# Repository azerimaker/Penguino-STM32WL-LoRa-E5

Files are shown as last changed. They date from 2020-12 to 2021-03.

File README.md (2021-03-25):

## Penguino-STM32WL-LoRa-E5
 Seeedstudio's [LoRa-E5 STM32WLE5JC](https://www.seeedstudio.com/LoRa-E5-Wireless-Module-p-4745.html) module was recently announced, and I took the liberty of designing a Penguino Feather breakout board for it. Hopefully OSHW community would benfit from it. 

## About the Penguino Feather breakout
Managed to fit everything on a +2 layer (H1.6mm) low-cost PCB. Careful design choices allowed to have a good GND plane on the back to to achieve good (theoretical) RF performance. 

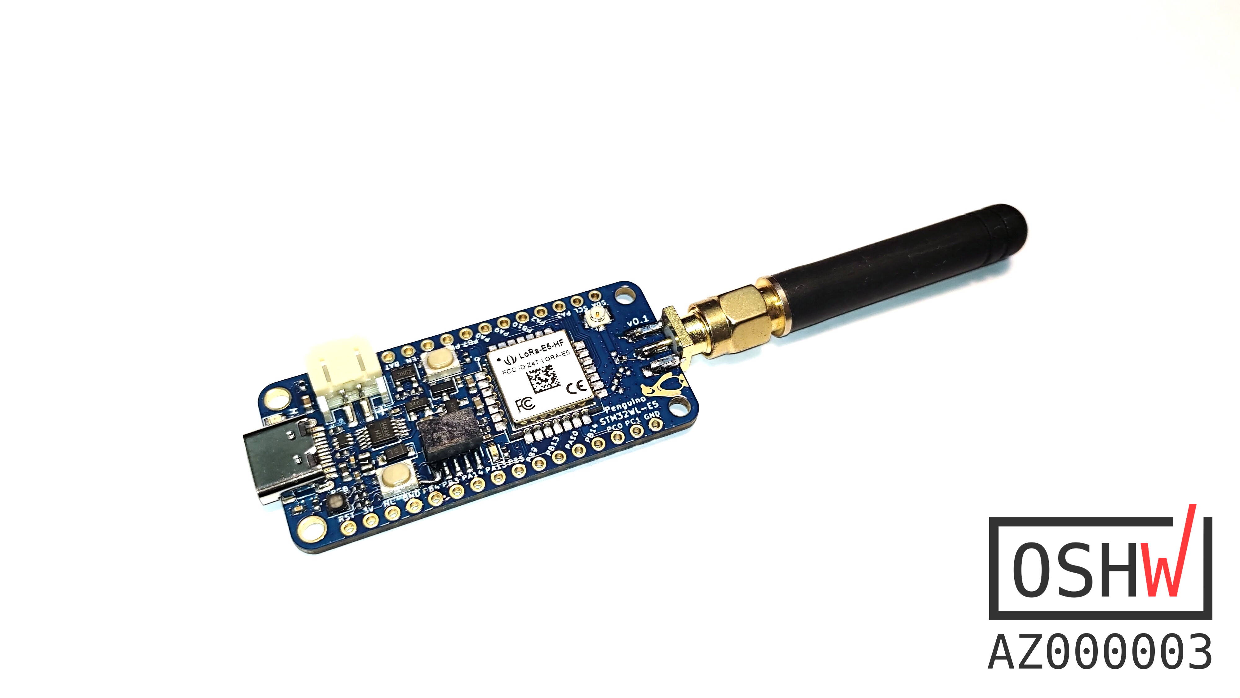
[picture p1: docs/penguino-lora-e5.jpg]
Penguino-STM32WL-LoRa-E5

_Current version: 0.1_

Board requirements are standard: 
- 6mil traces/clearance
- 0.3mm drill

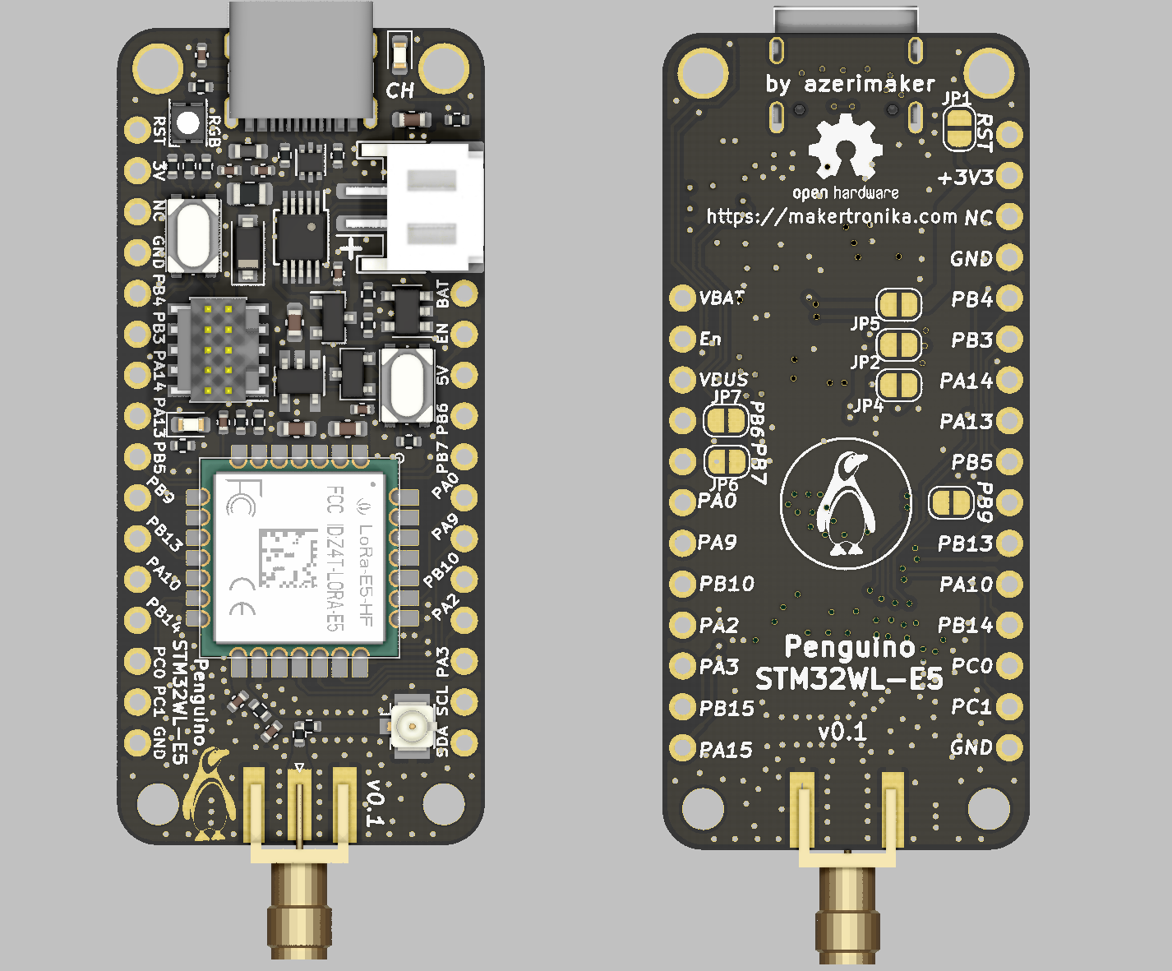
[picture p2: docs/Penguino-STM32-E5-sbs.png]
Penguino-STM32WL-LoRa-E5-back


### Specs (SoC): 
- [STM32WLE5JC](https://www.st.com/en/microcontrollers-microprocessors/stm32wle5jc.html) Wireless SoC
- ARM Cortex M4 ultra-low-power MCU
- Integrated SX1262 RF transciever
- Frequency range: 150 MHz to 960 MHz.
- Modulation: LoRa®, (G)FSK, (G)MSK and BPSK
- Transmitter power: programmable up to +22 dBm 

### Specs ([LoRa-E5 module](](https://www.seeedstudio.com/LoRa-E5-Wireless-Module-p-4745.html))): 
- Frequency range: EU868/US915/AU915/AS923/KR920/IN865 (high-band design). FCC and CE Certified
- Ultra-low Power Consumption: as low as 2.1uA sleep current (WOR mode)
- High Performance: TXOP=22dBm@868/915MHz; -136.5dBm sensitivity for SF12 with 125KHz BW 
- Long Distance Use: 158dB link budget
- Size: 12mm * 12mm * 2.5mm 28 pins SMT
- For further specs plese see the respective product pages. 

### License:
- Hardware license: CERN-OHL-S v2
- Software license: under MIT unless otherise indicated 
- Documentation license:  CC BY-SA 4.0 International.

OSHW License

## Open Source Hardware
This board is an OSHWA approved design: [AZ000003](https://certification.oshwa.org/az000003.html)

### Contact:
If you have any question or comments please feel free to open an issue (or a discussion or drop me a message at [@azerimaker](https://twitter.com/azerimaker).

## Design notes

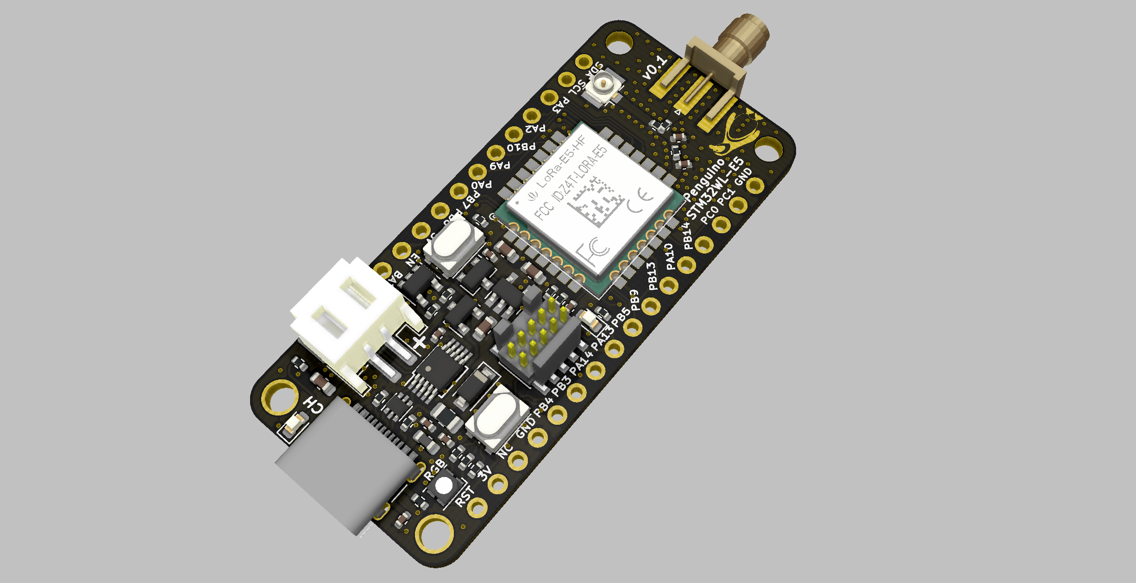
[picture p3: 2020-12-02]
docs/Penguino-STM32-E5.PNG

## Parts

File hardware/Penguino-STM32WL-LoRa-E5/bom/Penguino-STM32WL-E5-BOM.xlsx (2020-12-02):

Item | Qty | Reference(s) | MPN | MPN_ALT | Seeed SKU | Value | Footprint | URL
1 | 2 | C1, C2 | CC0402KRX7R9BB103 | ~ | 302010006 | 10nF | Capacitor_SMD:C_0402_1005Metric | https://lcsc.com/product-detail/Multilayer-Ceramic-Capacitors-MLCC-SMD-SMT_YAGEO-CC0402KRX7R9BB103_C60133.html
2 | 3 | C3, C5, C6 | CC0603KRX5R6BB106 | ~ | 302010103 | 10uF | Capacitor_SMD:C_0603_1608Metric | https://lcsc.com/product-detail/Others_YAGEO-CC0603KRX5R6BB106_C326057.html
3 | 4 | C4, C7, C10, C13 | GRM155R61A104KA01D | ~ | 302010037 | 100nF | Capacitor_SMD:C_0402_1005Metric | https://lcsc.com/product-detail/Multilayer-Ceramic-Capacitors-MLCC-SMD-SMT_Murata-Electronics-GRM155R61A104KA01D_C76997.html
4 | 1 | C8 | CC0603KRX5R6BB475 | ~ | 302010111 | 4.7uF | Capacitor_SMD:C_0603_1608Metric | https://lcsc.com/product-detail/Multilayer-Ceramic-Capacitors-MLCC-SMD-SMT_YAGEO-CC0603KRX5R6BB475_C109456.html
5 | 0 | C9, C11 | DNM | ~ |  | DNM | Capacitor_SMD:C_0402_1005Metric | ~
6 | 1 | D1 | 19-217-Y5C-AM1N1VY-3T | ~ | 304090044 | CH_YELLOW | LED_SMD:LED_0603_1608Metric | https://lcsc.com/product-detail/Others_Everlight-Elec-19-217-Y5C-AM1N1VY-3T_C282130.html
7 | 1 | D2 | B5819W | ~ | 304020034 | B5819W | Diode_SMD:D_SOD-123 | https://lcsc.com/product-detail/Schottky-Barrier-Diodes-SBD_AnBon-B5819W_C541627.html
8 | 1 | D3 | FM-B2020RGBA-HG | ~ | ~ | FM-B2020RGBA RGB LED | LED_SMD:LED_Cree-PLCC4_2x2mm_CW | https://lcsc.com/product-detail/Light-Emitting-Diodes-LED_Foshan-NationStar-Optoelectronics-FM-B2020RGBA-HG_C108793.html
9 | 1 | D4 | 19-217-BHC-ZL1M2RY-3T | ~ | 304090045 | PWR_BLUE | LED_SMD:LED_0603_1608Metric | https://lcsc.com/product-detail/Light-Emitting-Diodes-LED_0603-Blue-light_C72041.html
10 | 1 | F1 | SMD0805P075TF | ~ | ~ | 0.75A | Fuse:Fuse_0805_2012Metric | https://lcsc.com/product-detail/PTC-Resettable-Fuses_PTTC-Polytronics-Tech-SMD0805P075TF_C209732.html
11 | 1 | FB1 | MMZ1608B601CTAH0 | ~ | ~ | MMZ1608B601CTAH0 | Inductor_SMD:L_0603_1608Metric | https://lcsc.com/product-detail/Ferrite-Beads_TDK-MMZ1608B601CTAH0_C97120.html
12 | 1 | J1 | S2B-PH-SM4-TB(LF)(SN) | ~ | ~ | JST_PH | Connector_JST:JST_PH_S2B-PH-SM4-TB_1x02-1MP_P2.00mm_Horizontal | https://lcsc.com/product-detail/Wire-To-Board-Wire-To-Wire-Connector_JST-Sales-America-S2B-PH-SM4-TB-LF-SN_C295747.html
13 | 1 | J2 | TYPE-C-31-M-12 | ~ | ~ | USB_C_Receptacle_USB2.0 | Connector_USB:USB_C_Receptacle_Palconn_UTC16-G | https://lcsc.com/product-detail/USB-Connectors_Korean-Hroparts-Elec-TYPE-C-31-M-12_C165948.html
14 | 1 | J3 | 20021121-00010C4LF | ~ | ~ | Conn_ARM_JTAG_SWD_10 | penguino_v1:PinHeader_2x05_P1.27mm_Vertical_SMD_noPaste | https://lcsc.com/product-detail/Pin-Header-Female-Header_Amphenol-ICC_20021121-00010C4LF_Amphenol-ICC-20021121-00010C4LF_C150517.html
15 | 1 | J4 | U.FL-R-SMT-1(10) | ~ | 320111077 | U.FL/iPEX | Connector_Coaxial:U.FL_Hirose_U.FL-R-SMT-1_Vertical | https://lcsc.com/product-detail/RF-Connectors-Coaxial-Connectors_HRS-Hirose-U-FL-R-SMT-1-10_C88373.html
16 | 1 | J5 | BWSMA-KE-P001 | ~ | ~ | SMA-Edge-Mount | penguino_v1:SMA_J_P_X_ST_EM1_EdgeMount | https://lcsc.com/product-detail/RF-Connectors-Coaxial-Connectors_BAT-WIRELESS-BWSMA-KE-P001_C496550.html
17 | 0 | JP1 | DNM | ~ | ~ | RGB-Cut | Jumper:SolderJumper-2_P1.3mm_Bridged_RoundedPad1.0x1.5mm | ~
18 | 0 | JP2 | DNM | ~ | ~ | PWRLED-Cut | Jumper:SolderJumper-2_P1.3mm_Bridged_RoundedPad1.0x1.5mm | ~
19 | 0 | JP3 | DNM | ~ | ~ | ADC-PIN-Cut | Jumper:SolderJumper-2_P1.3mm_Bridged_RoundedPad1.0x1.5mm | ~
20 | 0 | JP4 | DNM | ~ | ~ | ADCV-Cut | Jumper:SolderJumper-2_P1.3mm_Bridged_RoundedPad1.0x1.5mm | ~
21 | 0 | JP5 | DNM | ~ | ~ | UART_VCC | Jumper:SolderJumper-2_P1.3mm_Bridged_RoundedPad1.0x1.5mm | ~
22 | 0 | JP6 | DNM | ~ | ~ | RX_CUT | Jumper:SolderJumper-2_P1.3mm_Bridged_RoundedPad1.0x1.5mm | ~
23 | 0 | JP7 | DNM | ~ | ~ | TX_CUT | Jumper:SolderJumper-2_P1.3mm_Bridged_RoundedPad1.0x1.5mm | ~
24 | 1 | Q1 | NCE3407A | ~ | 305030010 | NCE3407A | Package_TO_SOT_SMD:SOT-23 | https://lcsc.com/product-detail/MOSFET_Wuxi-NCE-Power-Semiconductor-NCE3407AY_C181919.html
25 | 2 | R1, R9 | RC0402JR-074K7L | ~ | 301010010 | 4K7 | Resistor_SMD:R_0402_1005Metric | https://lcsc.com/product-detail/Chip-Resistor-Surface-Mount_YAGEO-RC0402JR-074K7L_C105870.html
26 | 3 | R2, R13, R14 | RC0402JR-071ML | ~ | 301010009 | 1M | Resistor_SMD:R_0402_1005Metric | https://lcsc.com/product-detail/Chip-Resistor-Surface-Mount_YAGEO-RC0402JR-071ML_C93949.html
27 | 5 | R3, R5, R6, R7, R8 | RC0402JR-071K5L | ~ | 301010001 | 1K5 | Resistor_SMD:R_0402_1005Metric | https://lcsc.com/product-detail/Chip-Resistor-Surface-Mount_YAGEO-RC0402JR-071K5L_C114451.html
28 | 1 | R4 | RC0402JR-07100KL | ~ | 301010033 | 100K | Resistor_SMD:R_0402_1005Metric | https://lcsc.com/product-detail/Chip-Resistor-Surface-Mount_YAGEO-RC0402JR-07100KL_C106234.html
29 | 2 | R10, R15 | RC0402JR-070RL | ~ | 301010000 | 0R | Resistor_SMD:R_0402_1005Metric | https://lcsc.com/product-detail/Chip-Resistor-Surface-Mount_YAGEO-RC0402JR-070RL_C60485.html
30 | 2 | R11, R12 | RC0402FR-075K1L | ~ | 301010495 | 5K1 | Resistor_SMD:R_0402_1005Metric | https://lcsc.com/product-detail/Chip-Resistor-Surface-Mount_YAGEO-RC0402FR-075K1L_C105872.html
31 | 0 | R16 | DNM | ~ | ~ | DNM | Resistor_SMD:R_0402_1005Metric | ~
32 | 2 | SW1, SW2 | SKRPACE010 | ~ | ~ | RESE, USR_BTN | penguino_v1:SW_Push_SKRPACE010 | https://lcsc.com/product-detail/Tactile-Switches_ALPS-Electric-SKRPACE010_C139797.html
33 | 1 | U1 | MCP73831T-2ACI/OT | ~ | ~ | MCP73831 | Package_TO_SOT_SMD:SOT-23-5 | https://lcsc.com/product-detail/PMIC-Battery-Management_Microchip-Tech-MCP73831T-2ACI-OT_C424093.html
34 | 1 | U2 | RT9078-33GJ5 | ~ | ~ | RT9078-33GJ5 | Package_TO_SOT_SMD:TSOT-23-5 | https://lcsc.com/product-detail/Dropout-Regulators-LDO_Richtek-Tech-RT9078-33GJ5_C110427.html
35 | 1 | U3 | MAX809STRG | ~ | ~ | MAX809STRG | Package_TO_SOT_SMD:SOT-23 | https://lcsc.com/product-detail/Microprocessor-Microcontroller-Supervisors_ON-Semiconductor-MAX809STRG_C9965.html
36 | 1 | U4 | CH340E | ~ | ~ | CH340E | Package_SO:MSOP-10_3x3mm_P0.5mm | https://lcsc.com/product-detail/USB-ICs_WCH-Jiangsu-Qin-Heng-CH340E_C99652.html
37 | 1 | U5 | LoRa-E5-HF | ~ | ~ | STM32WL-LoRa-E5 | stm32wl-lib-v1:stm32wl-LoRa-E5-w-paste | https://www.seeedstudio.com/LoRa-E5-Wireless-Module-p-4745.html
38 | 1 | U7 | USBLC6-2P6 | ~ | ~ | USBLC6-2P6 | Package_TO_SOT_SMD:SOT-666 | https://lcsc.com/product-detail/Diodes-ESD_STMicroelectronics-USBLC6-2P6_C15999.html
Date: | 12/1/2020 7:00:41 PM
Tool: | Eeschema (5.1.8)-1
Component Count: | 45
Individual Components: | 38

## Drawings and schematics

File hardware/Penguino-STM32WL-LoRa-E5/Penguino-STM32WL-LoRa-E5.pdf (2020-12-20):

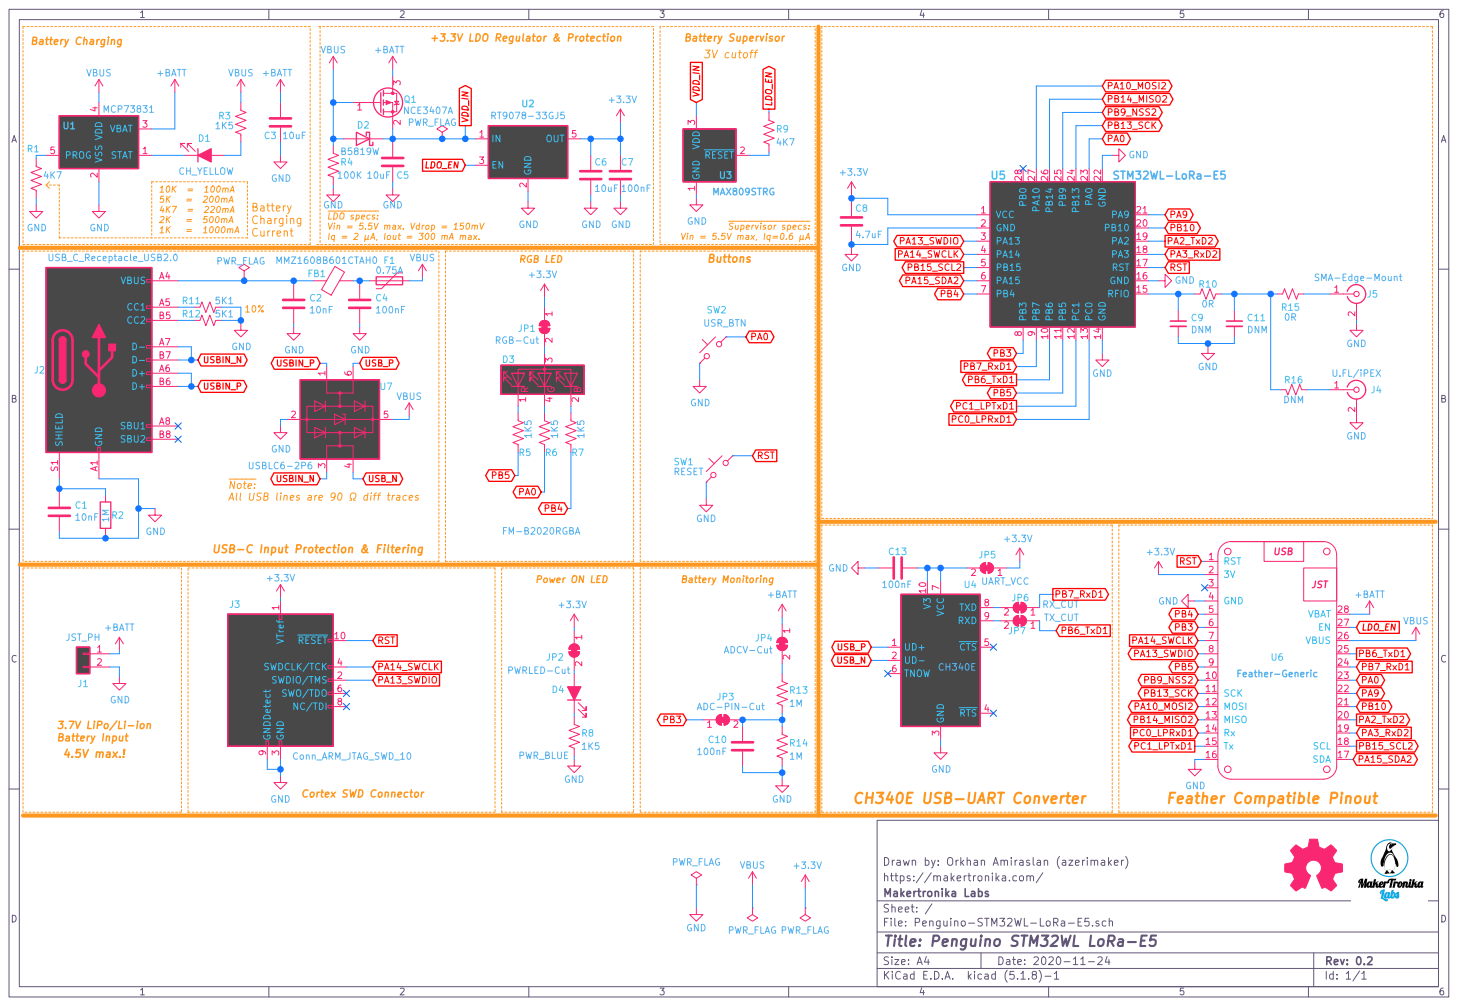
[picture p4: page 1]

JP4 ADCV-Cut+BATT GND GND

GND
Supervisor specs: Vin = 5.5V max, Iq=0.6 A

4.7uF GND
Iq = 2 A, Iout = 300 mA max.

3 RTS 4 CTS 5 TNOW 6 VCC

3 SWDCLK/TCK 4 SWO/TDO 6 NC/TDI 8 GNDDetect 9

Drawn by: Orkhan Amiraslan (azerimaker) C10

https://makertronika.com/
File: Penguino-STM32WL-LoRa-E5.sch Sheet: / Makertronika Labs

Id: 1/1 Title: Penguino STM32WL LoRa-E5

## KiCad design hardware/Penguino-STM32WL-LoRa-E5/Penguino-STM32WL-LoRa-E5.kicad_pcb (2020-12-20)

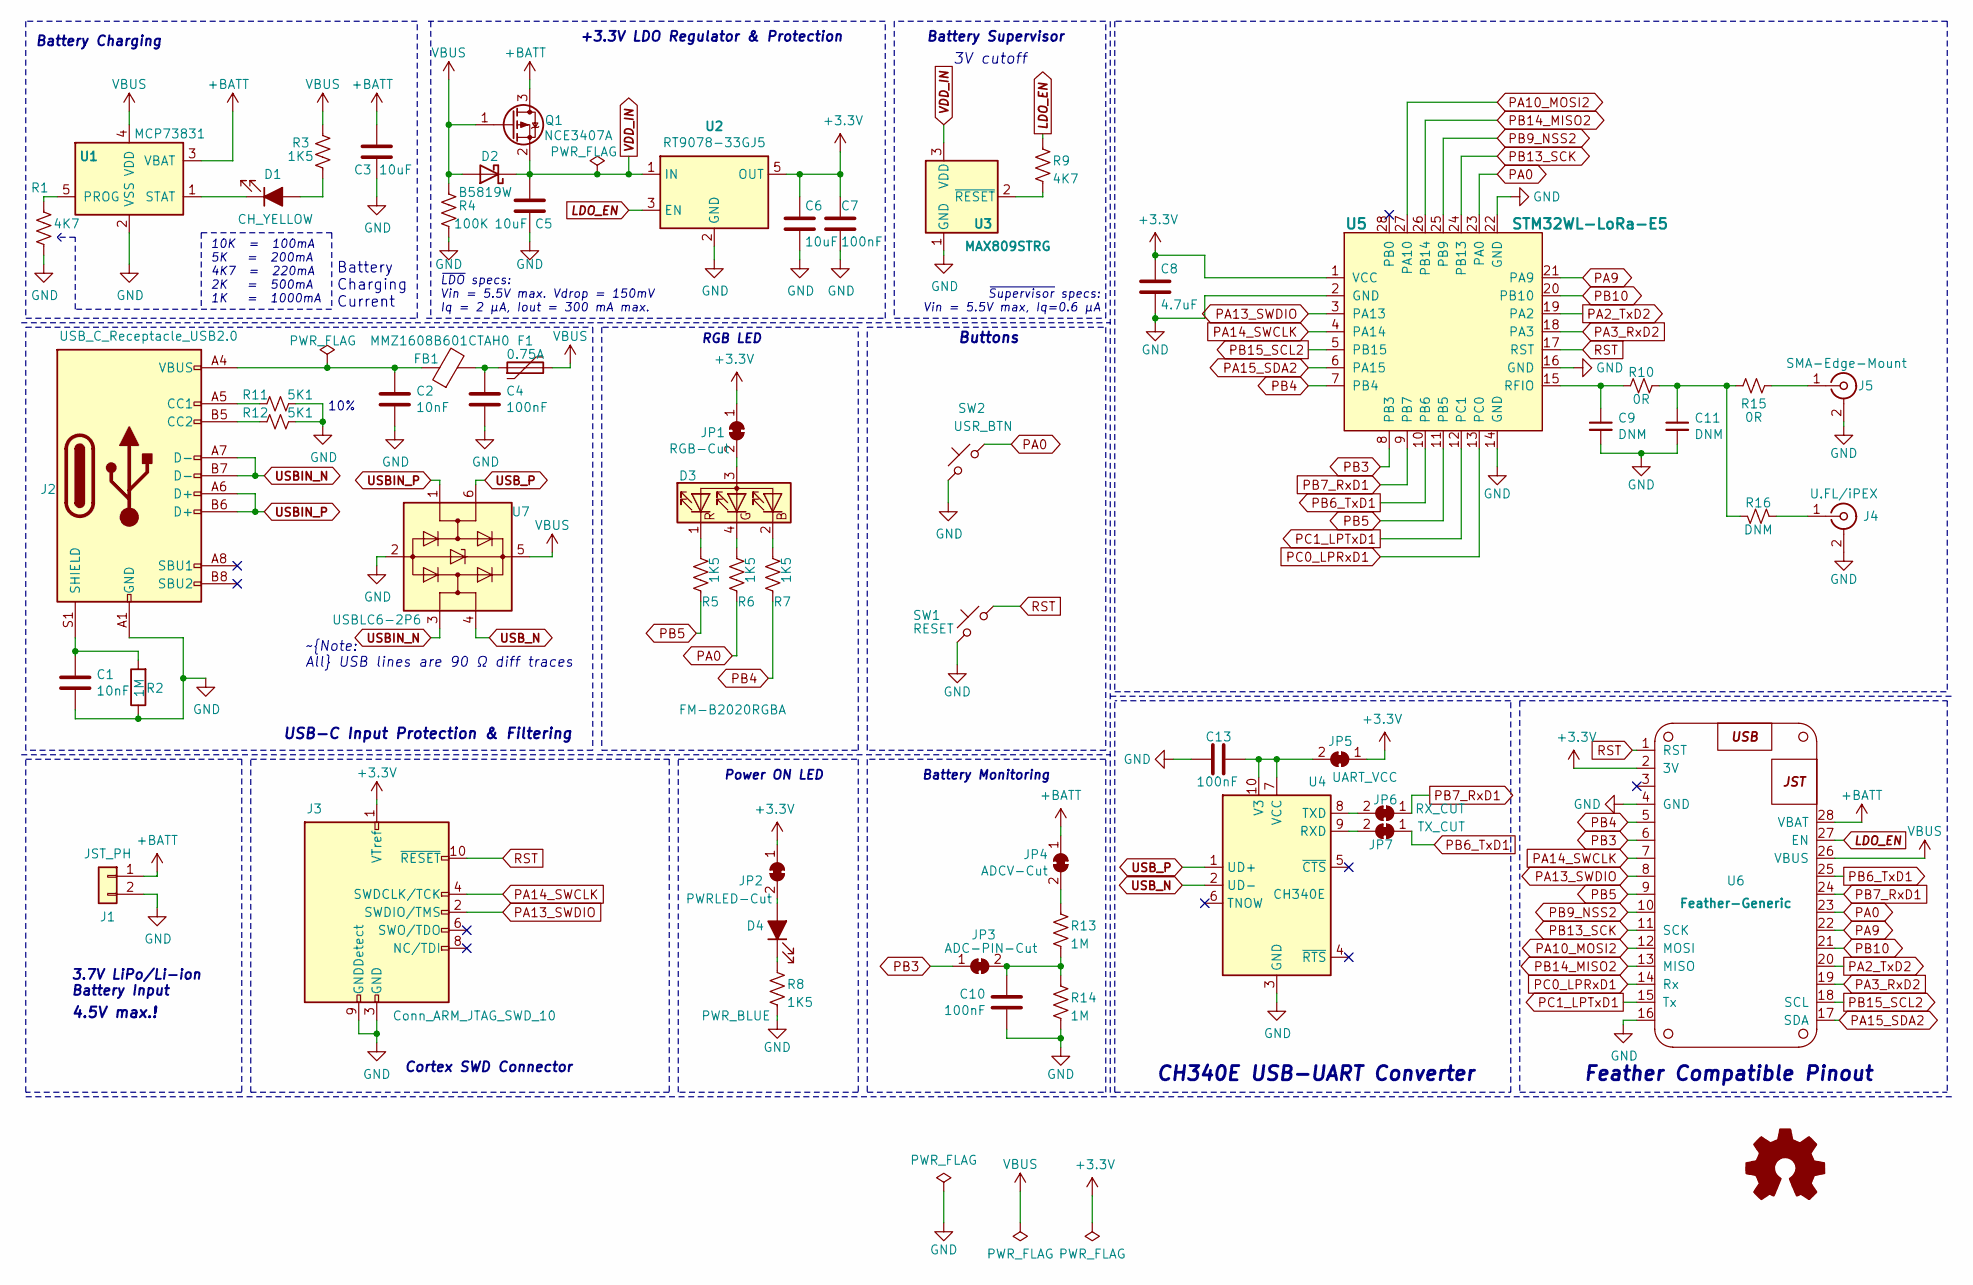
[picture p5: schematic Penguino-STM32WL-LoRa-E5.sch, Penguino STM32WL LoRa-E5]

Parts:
C1, C2: 10nF; C_0402_1005Metric; MPN CC0402KRX7R9BB103; LCSC_Part# C57112
C3, C5, C6: 10uF; C_0603_1608Metric; MPN CC0603KRX5R6BB106; LCSC_Part# C19702
C4, C7: 100nF; C_0402_1005Metric; MPN GRM155R61A104KA01D; LCSC_Part# C14663
C8: 4.7uF; C_0603_1608Metric; MPN CC0603KRX5R6BB475
C9, C11: DNM; C_0402_1005Metric; MPN DNM
C10, C13: 100nF; C_0402_1005Metric; MPN GRM155R61A104KA01D; LCSC_Part# C1525
D1: CH_YELLOW; LED_0603_1608Metric; MPN 19-217-Y5C-AM1N1VY-3T; LCSC_Part# C375450
D2: B5819W; D_SOD-123; MPN B5819W
D3: FM-B2020RGBA; LED_Cree-PLCC4_2x2mm_CW; MPN FM-B2020RGBA-HG; LCSC_Part# C108793
D4: PWR_BLUE; LED_0603_1608Metric; MPN 19-217-BHC-ZL1M2RY-3T; LCSC_Part# C72041
F1: 0.75A; Fuse_0805_2012Metric; MPN SMD0805P075TF; LCSC_Part# C20979
FB1: MMZ1608B601CTAH0; L_0603_1608Metric; MPN MMZ1608B601CTAH0; LCSC_Part# C98286
J1: JST_PH; JST_PH_S2B-PH-SM4-TB_1x02-1MP_P2.00mm_Horizontal; MPN S2B-PH-SM4-TB(LF)(SN)
J2: USB_C_Receptacle_USB2.0; USB_C_Receptacle_HRO_TYPE-C-31-M-12; MPN TYPE-C-31-M-12
J3: Conn_ARM_JTAG_SWD_10; PinHeader_2x05_P1.27mm_Vertical_SMD_noPaste; MPN 20021121-00010C4LF
J4: U.FL/iPEX; U.FL_Hirose_U.FL-R-SMT-1_Vertical; MPN U.FL-R-SMT-1(80)
J5: SMA-Edge-Mount; SMA_J_P_X_ST_EM1_EdgeMount; MPN DNM
JP1: RGB-Cut; SolderJumper-2_P1.3mm_Bridged_RoundedPad1.0x1.5mm; MPN DNM
JP2: PWRLED-Cut; SolderJumper-2_P1.3mm_Bridged_RoundedPad1.0x1.5mm; MPN DNM
JP3: ADC-PIN-Cut; SolderJumper-2_P1.3mm_Bridged_RoundedPad1.0x1.5mm; MPN DNM
JP4: ADCV-Cut; SolderJumper-2_P1.3mm_Bridged_RoundedPad1.0x1.5mm; MPN DNM
JP5: UART_VCC; SolderJumper-2_P1.3mm_Bridged_RoundedPad1.0x1.5mm; MPN DNM
JP6: RX_CUT; SolderJumper-2_P1.3mm_Bridged_RoundedPad1.0x1.5mm; MPN DNM
JP7: TX_CUT; SolderJumper-2_P1.3mm_Bridged_RoundedPad1.0x1.5mm; MPN DNM
Q1: NCE3407A; SOT-23; MPN NCE3407A; LCSC_Part# C2593
R1, R9: 4K7; R_0402_1005Metric; MPN RC0402JR-074K7L; LCSC_Part# C25900
R2, R13: 1M; R_0402_1005Metric; MPN RC0402JR-071ML; LCSC_Part# C26083
R3, R5, R6, R7, R8: 1K5; R_0402_1005Metric; MPN RC0402JR-071K5L; LCSC_Part# C25862
R4: 100K; R_0402_1005Metric; MPN RC0402JR-07100KL; LCSC_Part# C25741
R10, R15: 0R; R_0402_1005Metric; MPN RC0402JR-070RL
R11, R12: 5K1; R_0402_1005Metric; MPN RC0402FR-075K1L
R14: 1M; R_0402_1005Metric; MPN RC0402JR-071ML
R16: DNM; R_0402_1005Metric; MPN DNM
SW1: RESET; SW_Push_SKRPACE010; MPN SKRPACE010
SW2: USR_BTN; SW_Push_SKRPACE010; MPN SKRPACE010
U1: MCP73831; SOT-23-5; MPN MCP73831T-2ACI/OT; LCSC_Part# C424093
U2: RT9078-33GJ5; TSOT-23-5; MPN RT9078-33GJ5; LCSC_Part# C110427
U3: MAX809STRG; SOT-23; MPN MAX809STRG; LCSC_Part# C9965
U4: CH340E; MSOP-10_3x3mm_P0.5mm; MPN CH340E; LCSC_Part# C99652
U5: STM32WL-LoRa-E5; stm32wl-LoRa-E5-w-paste; MPN LoRa-E5-HF
U6: Feather-Generic
U7: USBLC6-2P6; SOT-666; MPN USBLC6-2P6

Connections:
+3V3: C6.1, C7.1, C8.1, J3.1 (VTref), JP1.1 (A), JP2.1 (A), JP5.1 (A), U2.5 (OUT), U5.1 (VCC), U6.2 (3V)
+BATT: C3.1, J1.1, JP4.1 (A), Q1.3 (D), U1.3 (VBAT), U6.28 (VBAT)
GND: C1.1, C2.2, C3.2, C4.2, C5.2, C6.2, C7.2, C8.2, C9.2, C10.1, C11.2, C13.2, J1.2, J2.A1 (GND), J2.A12 (GND), J2.B1 (GND), J2.B12 (GND), J3.3 (GND), J3.5 (GND), J3.9 (GNDDetect), J4.2 (Ext), J5.2 (Ext), R1.2, R2.1, R4.2, R8.2, R11.1, R12.1, R14.2, SW1.1, SW2.1, U1.2 (VSS), U2.2 (GND), U3.1 (GND), U4.3 (GND), U5.2 (GND), U5.14 (GND), U5.16 (GND), U5.22 (GND), U6.4 (GND), U6.16, U7.2 (GND)
LDO_EN: R9.1, U2.3 (EN), U6.27 (EN)
unnamed: C1.2, J2.S1 (SHIELD), R2.2
unnamed: C2.1, FB1.1, J2.A4 (VBUS), J2.A9 (VBUS), J2.B4 (VBUS), J2.B9 (VBUS)
unnamed: C4.1, F1.1, FB1.2
unnamed: C9.1, R10.2, U5.15 (RFIO)
unnamed: C10.2, JP3.2 (B), R13.2, R14.1
unnamed: C11.1, R10.1, R15.2, R16.1
unnamed: C13.1, JP5.2 (B), U4.7 (VCC), U4.10 (V3)
unnamed: D1.1 (K), U1.1 (STAT)
unnamed: D1.2 (A), R3.2
unnamed: D3.1 (RK), R5.1
unnamed: D3.2 (BK), R7.1
unnamed: D3.3 (A), JP1.2 (B)
unnamed: D3.4 (GK), R6.1
unnamed: D4.1 (K), R8.1
unnamed: D4.2 (A), JP2.2 (B)
unnamed: J2.A5 (CC1), R11.2
unnamed: J2.B5 (CC2), R12.2
unnamed: J4.1 (In), R16.2
unnamed: J5.1 (In), R15.1
unnamed: JP4.2 (B), R13.1
unnamed: JP6.2 (B), U4.8 (TXD)
unnamed: JP7.2 (B), U4.9 (RXD)
unnamed: R1.1, U1.5 (PROG)
unnamed: R9.2, U3.2 (~RESET)
PA0: R6.2, SW2.2, U5.23 (PA0), U6.23
PA2_TxD2: U5.19 (PA2), U6.20
PA3_RxD2: U5.18 (PA3), U6.19
PA9: U5.21 (PA9), U6.22
PA10_MOSI2: U5.27 (PA10), U6.12 (MOSI)
PA13_SWDIO: J3.2 (SWDIO/TMS), U5.3 (PA13), U6.8
PA14_SWCLK: J3.4 (SWDCLK/TCK), U5.4 (PA14), U6.7
PA15_SDA2: U5.6 (PA15), U6.17 (SDA)
PB3: JP3.1 (A), U5.8 (PB3), U6.6
PB4: R7.2, U5.7 (PB4), U6.5
PB5: R5.2, U5.11 (PB5), U6.9
PB6_TxD1: JP7.1 (A), U5.10 (PB6), U6.25
PB7_RxD1: JP6.1 (A), U5.9 (PB7), U6.24
PB9_NSS2: U5.25 (PB9), U6.10
PB10: U5.20 (PB10), U6.21
PB13_SCK: U5.24 (PB13), U6.11 (SCK)
PB14_MISO2: U5.26 (PB14), U6.13 (MISO)
PB15_SCL2: U5.5 (PB15), U6.18 (SCL)
PC0_LPRxD1: U5.13 (PC0), U6.14 (Rx)
PC1_LPTxD1: U5.12 (PC1), U6.15 (Tx)
RST: J3.10 (~RESET~), SW1.2, U5.17 (RST), U6.1 (RST)
USBIN_N: J2.A7 (D-), J2.B7 (D-), U7.3 (I/O2)
USBIN_P: J2.A6 (D+), J2.B6 (D+), U7.1 (I/O1)
USB_N: U4.2 (UD-), U7.4 (I/O2)
USB_P: U4.1 (UD+), U7.6 (I/O1)
VBUS: D2.2 (A), F1.2, Q1.1 (G), R3.1, R4.1, U1.4 (VDD), U6.26 (VBUS), U7.5 (VBUS)
VDD_IN: C5.1, D2.1 (K), Q1.2 (S), U2.1 (IN), U3.3 (VDD)

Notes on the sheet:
10K = 100mA 5K = 200mA 4K7 = 220mA 2K = 500mA 1K = 1000mA
3.7V LiPo/Li-ion Battery Input
Battery Charging
USB-C Input Protection & Filtering
RGB LED
Battery Monitoring
Cortex SWD Connector
~Note: All USB lines are 90 Ω diff traces
Buttons
+3.3V LDO Regulator & Protection
Battery Supervisor
~LDO specs: Vin = 5.5V max. Vdrop = 150mV Iq = 2 μA, Iout = 300 mA max.
3V cutoff
~Supervisor specs: Vin = 5.5V max, Iq=0.6 μA
4.5V max.!
Feather Compatible Pinout
Power ON LED
CH340E USB-UART Converter
Battery Charging Current
10%

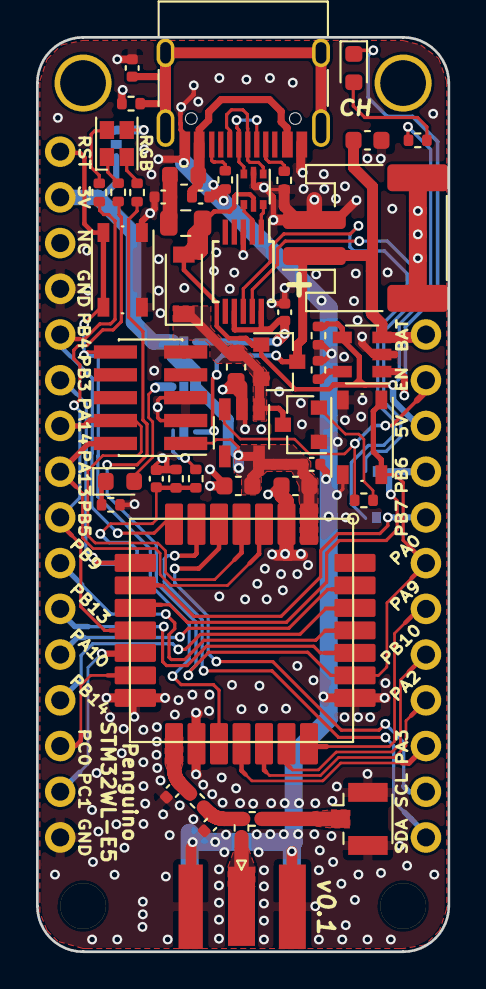
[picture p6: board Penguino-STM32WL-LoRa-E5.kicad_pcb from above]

Board: 2 copper layers, 22.9 x 50.8 mm, 57 parts (0 on the bottom side), 55 nets.

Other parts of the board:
G-Penguino: LOGO; Penguino-SM-5500

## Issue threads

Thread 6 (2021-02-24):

Archive of files needed to build it ?

vincegre, 2021-02-24:
Hi

Very interested by your nice design but not sure what files I should send at manufacturer to get it built as it asks for gerber and BOM. May you please let me know files I need and requisite for manufacturer to build the board and do components assembly ?

Thanks

Vincèn

azerimaker, 2021-02-24:
Hi, thanks for your contact.

All the files you need are in the [fabrication ](https://github.com/azerimaker/Penguino-STM32WL-LoRa-E5/tree/main/hardware/Penguino-STM32WL-LoRa-E5/fabrication) folder.

Just zip the gerber folder and submit it alongside the BOM excel file.

Hope it helps.

Cheers,

Orkhan

vincegre, 2021-02-24:
Hi Orkhan

Thanks for your so fast answer ;) I have succeeded to upload the gerber zip as advised as Seeed Fusion service but the BOM is not in valid format for Seeed website :( I'll check later what's the problem and let you know. Was it used with Seeed Fusion service ? as I see you have listed Seeed SKU for most parts !

Cheers

Vincèn

azerimaker, 2021-02-24:
My pleasure.

They have a slightly different BOM template, which I already modified. You can use this file:

[Penguino-STM32WL-E5-BOM_short_Seeed.xlsx](https://github.com/azerimaker/Penguino-STM32WL-LoRa-E5/files/6035477/Penguino-STM32WL-E5-BOM_short_Seeed.xlsx)

Cheers,

Orkhan

vincegre, 2021-02-24:
> They have a slightly different BOM template, which I already modified. You can use this file:
> [Penguino-STM32WL-E5-BOM_short_Seeed.xlsx](https://github.com/azerimaker/Penguino-STM32WL-LoRa-E5/files/6035477/Penguino-STM32WL-E5-BOM_short_Seeed.xlsx)

Thanks a lot for the updated file (perhaps put it aside the original one in repository no ?) and I have been able to submit whole job at Seeed, I'm waiting for answer from them !

Cheers

Vincèn

azerimaker, 2021-02-24:
>  (perhaps put it aside the original one in repository no ?)

will do so. Thanks.

Good luck with the production.

vincegre, 2021-02-24:
> Good luck with the production.

Thanks, will update you when I have received the boards from Seeed ;)

Closed 2021-02-24.

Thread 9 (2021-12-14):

How to dimension C9, C11 and R10

simon88, 2021-12-14:
Hi,

Nice works, I'm interresting to use it but I have a question, how to dimension  C9, C11 and R10 for RF part?

azerimaker, 2021-12-14:
Hi, @simon88.

Thank you for interest. C9, C11 and R10 forms a circuit which is typically called a Pi matching network, in this case to match the impedance of the RF module (*typically 50 Ohms) to the antenna (can vary significantly depending on the quality).
If you have a well matched antenna then you can simply short R10 with 0 Ohm resistor and leave others unpopulated.

Otherwise, you need a Vector Network Analyzer (VNA) to properly measure the impedance of the antenna while the device is installed on its final enclosure and use online calculator like [this one](https://www.allaboutcircuits.com/tools/pi-match-impedance-matching-calculator/) to calculate the exact inductor and capacitor values.

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

simon88, 2021-12-14:
@azerimaker thanks a lot for this very useful answer :)

Closed 2021-12-14.

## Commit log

2020-12-02 Readme update, rev01 design files
    [Penguino-STM32WL-E5-BOM.xlsx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]
2020-12-20 fix: NRST and USB Footprint
    [Penguino-STM32WL-LoRa-E5.kicad_pcb, Penguino-STM32WL-LoRa-E5.sch]
2020-12-20 fix: PDF Schematics
2020-12-21 fix: Gerber update
    [Penguino-STM32WL-LoRa-E5-B_Mask.gbs, Penguino-STM32WL-LoRa-E5-B_Paste.gbp, Penguino-STM32WL-LoRa-E5-B_SilkS.gbo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]
2021-04-09 doc: Add iBOM file
    [Penguino-STM32WL-E5-BOM.xlsx]
